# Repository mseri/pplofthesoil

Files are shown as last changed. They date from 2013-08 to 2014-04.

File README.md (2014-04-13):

# People of the Soil
**(co-winners of the London Nasa Space Apps Challenge 2013)** 

During the Space Apps Challenge 2013, at the Google Campus in London, we have developed **Project Soil**: an extremely cheap and easy to use system to collect and manage soil data.

People of the Soil in London

We kept in mind that not all the world is as lucky as us and there are plenty of places where internet is slow or completely absent and where there is much less money around. 

**Project Soil** is an open system that includes:

- an extremely cheap (~3£) digital soil testing kit to collect data, and eventually send it
- a light protocol to send the data using web, apps or even SMS and collect it on a centralised database
- an API to disseminate information via SMS or web
- a wonderful and light web application that can run on old and recent phones and gives access to the data with a simple and nice interface.

# Project Soil

We spent the first part of the challeng looking at all our different backgrounds and skills and reformulating the challenge in a series of smaller ones that we feelt we could face. 

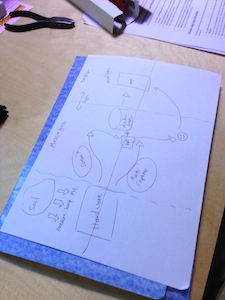
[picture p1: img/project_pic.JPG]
First drafto of Project Soil


As you can see from the image below, **Project Soil** is made by three big interlaced projects, each of them with a particular focus: acquiring data, collecting it and make it available.

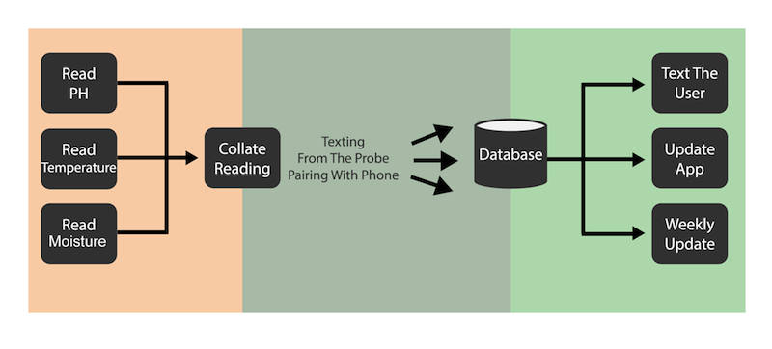
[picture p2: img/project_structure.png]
Project Soil in bites


## The probe

In this part of the projected we aimed to create a proof-of-concept soil testing kit that could be miniaturised and mass produced. This can then upload recorded soil data, taken over a period of several weeks, to a central database via a phone application or computer interface.

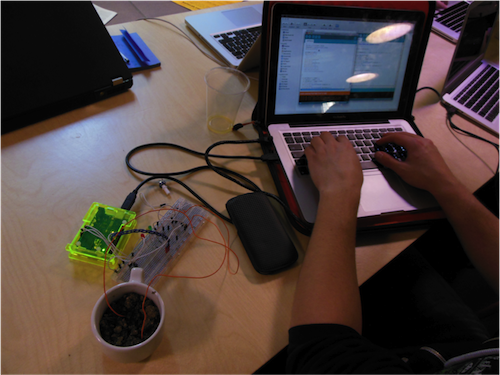
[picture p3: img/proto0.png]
The Probe v0.1


The hardware team realized in an amazingly short time a working prototype of probe to collect soil data. In the first version an Arduino was collecting data from various sensors and sending it to a Rasperry Pi programmed to forward it to our database.

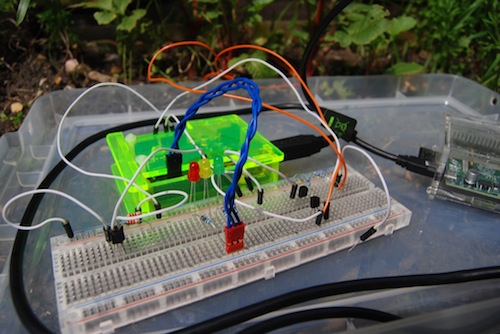
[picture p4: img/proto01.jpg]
Testing the Probe v0.1


In addition, the aim was to create a PCB schematic and layout to implement this system realistically and cost such a device. CAD models were created to aid development and concept presentation.

The project uses a DS18B20 temperature sensor and a transistor amplified simple moisture sensor.

Moisture is displayed as an estimated percentage volume of water to soil. Completely soaked soil will hold up to around 50% water content and so a measurement of resistance of pure water is taken as the calibration mark for 50% and the probe held in air is taken as the calibration for 0%.

The hardware prototype is a proof of concept, a final device should use a much cheaper MPU such as an ATMEGA48A-MU 4K memory, 8-Bit MPU. This can be sourced (in bulk) for less than 80p per unit.

### The probe and its price breakdown

In fact, from that prototype the hardware team engineered a small and cheap device that you can simply plug in the field and leave alone collecting the data. Afterward it is enough to have a USB connection to collect the data and send it to our servers.

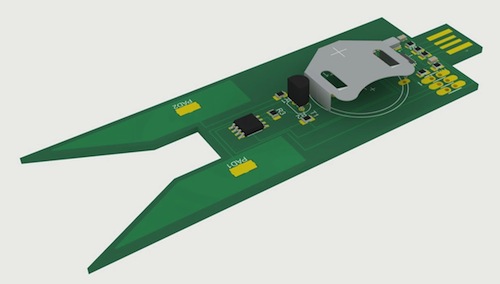
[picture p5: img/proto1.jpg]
The Probe v.1.1 - PCB


For whom may be interested, the price of the final device can be overestimated as follows:

- ATMEGA48A £0.80   
- Resistor £0.10   
- DS18B20 £0.85   
- CR2032 Coin Cell £0.39   
- Coin cell holder £0.20   
- PCB manufacture £1.00   

**Total £3.34**

## The SMS service

Keeping in mind that not all the world is covered by internet, we used the twilio API to create a service to send the data directly through SMS. This makes it good for use in more developing regions of the world.

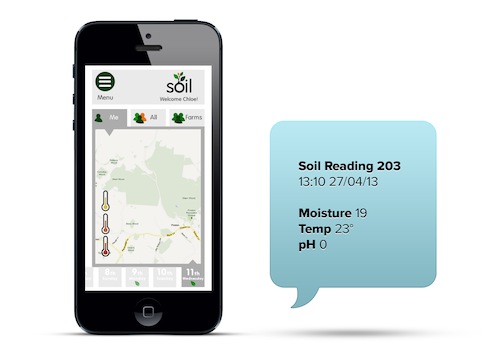
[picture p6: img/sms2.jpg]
A small screenshot of the webapp and the SMS service


Send a text to _01952 787011_ containing a list of readings for the following parameters pH, temperature, moisture, lat/latitude and long/longitude and then will be added to the dataset. The list of key, values can be separated by whitespace or , delimited and the order doesn't matter

```
pH = 7.2, lat=51.9972, long=-0.7421, temp=35
```

You will receive back a message confirming the data your sent and that it had been saved to the database.

## Data collection

While the SMS data goes directly to the database, all the rest of the communication is made by means of [MQTT](http://mqtt.org), a machine-to-machine (M2M)/"Internet of Things" connectivity protocol designed to be extremely lightweight. In this way we can move all the management of the data to our server and consume as less power and bandwith as possible on the clients.

## Web App

Again keeping in mind to consume as less bandwith as possible, we designed and developed an extremely intuitive and nice application, completely based on HTML and CSS, and with nearly no image. In this way people can access the data using any device, not just the last generation of smartphones, consuming nearly no bandwidth!

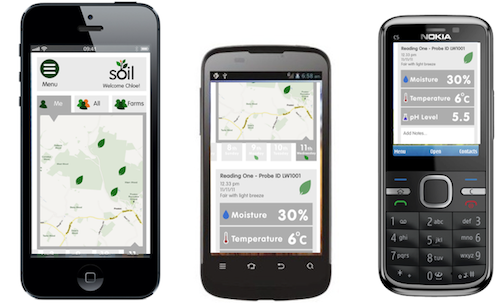
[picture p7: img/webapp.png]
Web App


You can already test our web app going to [Project Soil App](http://www.soil-app.appspot.com/)

## Ideas for the future
The possible implications and improvement for the future are the most variuos. Here there is a small list of what we could and would like to achieve:

- Implementations of more chemical and pH sensors could be made extremely cheaply and in bulk by using thick film printing processes. _This could be an avenue for further development although the technology is still heavily in it's infancy._
- Improve the probe to make it cheaper, stronger and with longer battery life.
- Add wifi/bluetooth/NFC capability to a bigger version of the probe that would not require laptop, smartphones or raspberry pi to send the data.
- Create an easy to use application to collect and send the data from probes that cannot be connected to wifi or bluetooth networks.
- Make the system independent from us and working on a global scale.
- Add some finer controls on the database to avoid fake data.
- Implement a robust and flexible API to make the soil data available to researchers and any other in need.
- Improve the Web App to include data analysis, comparisons and infographics.
- Add support to other languages.
- Go to other planet (see below).

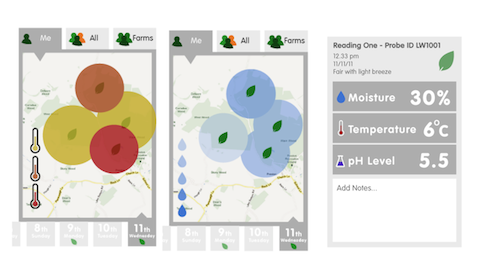
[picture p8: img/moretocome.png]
More to come on the web app


## Project Soil on other Planets
And with our small collaboration with solsola we are ready to fly on the space and collect extra terrestrial soil data!

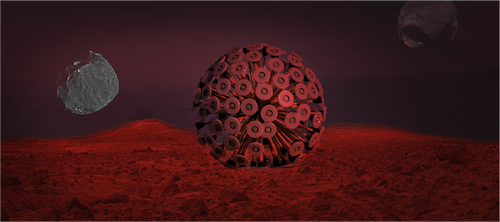
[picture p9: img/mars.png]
Solsola and Project Soil on Mars


# More Images and Informations

Look what we did going to the [Git Hub page](https://github.com/mseri/pplofthesoil), looking for our [hashtag #pplofthesoil](http://bit.ly/124FU89) on Twitter, watching our [presentation](http://bit.ly/ZIbJ3x) or reading our ["storified" weekend story](http://bit.ly/17dYVqT)

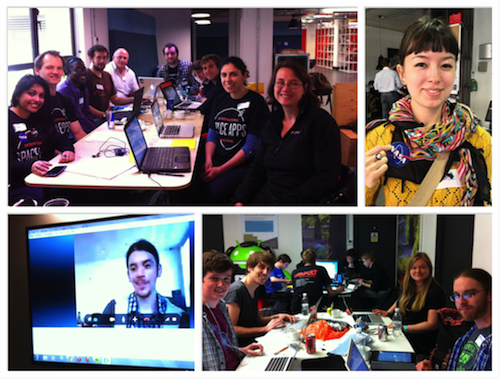
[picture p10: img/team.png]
Our Team


Additionally you can read:  
- [Our video on Vimeo](http://vimeo.com/65080796)  
- [Soil Testing Kit Challenge](http://spaceappschallenge.org/challenge/soil-testing-kit)
- [People of the Soil -- Project Page](http://spaceappschallenge.org/project/people-of-the-soil/)

Congratulation to all the [winners of the 2013 International Space Apps Challenge](http://open.nasa.gov/blog/2013/05/22/global-award-winners-for-the-2013-international-space-apps-challenge/). 
We didn't win but we've got a Honorable Mention on the Global Impact category!!!!

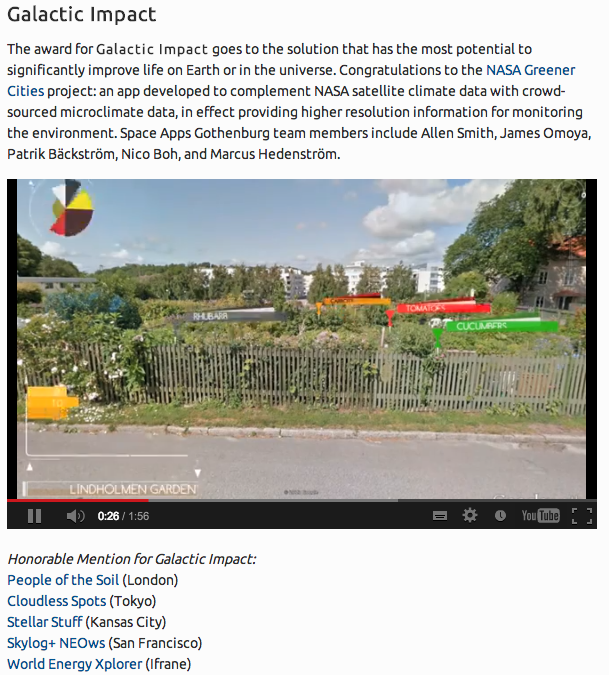
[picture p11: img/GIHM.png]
Honorable Mention for Project Soil


And thanks to Ben's committment, we have a new, nice and cheap printed Soil PCB:
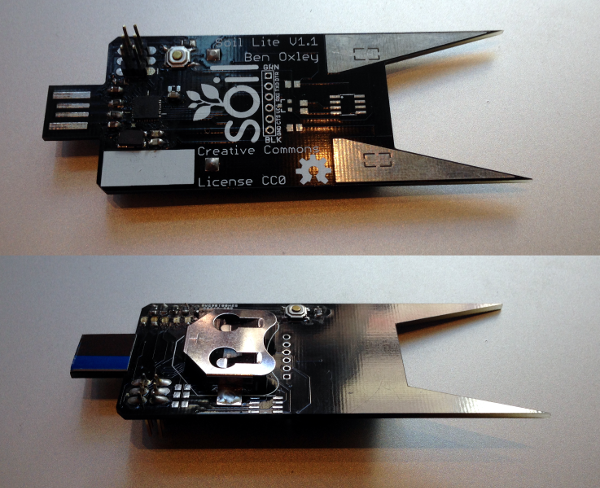
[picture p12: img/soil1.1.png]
We have a new printed version of the Soil Probe - Thanks Ben


* * * * * * * 

The Git repository contains:

- The **presentation** of our work: *SOILPres-v3.pdf*
- The full implementation of the **probe** (hardware and software) and the **PCB** schematic to build a cheap and effective probe: *probe* folder
- The interface to the **MQTT** service that translates the data and sends it to the DB: *MQTTinterface* folder
- The **DB and SMS** service (hosted on another Git repo): *text-message-and-database-api* folder
- The **mobile app** to have access to the data: *mobileapp* folder
- A folder **img** with the pictures used in this README files

The project is released under Eclipse Public License 1.0

* * * * * * * * * *    
* * * * * * * * * *    

# Something more technical for us and potential collaborators

## Data structure

Data readings are of the form  

{  
    "id": "182791",  
    "time": "13:56:13 20/04/2013",  
    "lat": "97.03125",  
    "long": "107.2890",  
    "hasAltitude":true,  
    "altitude": "10",  
    "hasPH":true,  
    "pH":"7",  
    "hasMoisture":true,  
    "moisture":"97",  
    "hasTemperature":true,  
    "temperature":"40"  
}  

and must be sent to
- MQTT Broker: m2m.eclipse.org:1833
- Topic: /pots/soil

id, time, lat, long MUST be present and not NULL, otherwise the data is sent directly to /dev/null

It can be done as simple and boring as using <http://mqtt.io/>    
Or you can let your hardware prepare the data and send it using (more or less) any programming language: <http://mqtt.org/software>

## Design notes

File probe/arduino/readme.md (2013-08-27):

# Arduino Code for PeopleOfTheSoil

It runs on an AVR with an arduino bootloader.

This project is being created in association with the google/NASA space apps challenge. 

#Roles
This part of the projected aimed to create a proof-of-concept soil testing kit that
could be miniaturised and mass produced. This can then upload recorded soil data, 
taken over a period of several weeks, to a central database via a phone application
or computer interface.

In addition, the aim was to create a PCB schematic and layout to implement this system
realistically and cost such a device.

CAD models were created to aid development and concept presentation.

#Scope
The views and conclusions contained in the software and documentation are those
of the authors and should not be interpreted as representing official policies, 
either expressed or implied, of the FreeBSD Project.

Project has used the OneWire library to communicate with a DS18B20 temperature 
sensor and a transistor amplified simple moisture sensor.

Moisture is displayed as an estimated percentage volume of water to soil. 
Completely soaked soil will hold up to around 50% water content and so a measurement 
of resistance of pure water is taken as the calibration mark for 50% and the probe 
held in air is taken as the calibration for 0%.

The hardware prototype is a proof of concept, a final device should use a much cheaper
MPU such as an ATMEGA48A-MU 4K memory, 8-Bit MPU. This can be sourced (in bulk) for 
less than 80p per unit.

##Further Work
Implementations of more chemical and pH sensors could be made extremely cheaply and in
bulk by using thick film printing processes. This could be an avenue for further 
development although the technology is still heavily in it's infancy.

## Links
* [Homepage](http://www.benoxley.com/) www.benoxley.com

<p xmlns:dct="http://purl.org/dc/terms/" xmlns:vcard="http://www.w3.org/2001/vcard-rdf/3.0#">
  <a rel="license"
     href="http://creativecommons.org/publicdomain/zero/1.0/">
    
  </a>
  <br />
  To the extent possible under law,
  <a rel="dct:publisher"
     href="www.benoxley.co.uk">
    <span property="dct:title">Ben Oxley</span></a>
  has waived all copyright and related or neighboring rights to
  <span property="dct:title">People of the Soil</span>.
This work is published from:
<span property="vcard:Country" datatype="dct:ISO3166"
      content="GB" about="www.benoxley.co.uk">
  United Kingdom</span>.
</p>

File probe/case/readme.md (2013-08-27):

#Case Designs for PeopleOfTheSoil

The 3D model is a mock up of how the final soil sensor could look. For reference, the small tab at the top represents a USB port (for connection to a phone or separate module for data transmission), the prongs at the bottom would ultimately be coated in a conductive material. The dimensions of the model are ~100 x  40 x ~17.5 mm.

In order to make it suitable for 3D printing, some compromises have been made, such as the way that prongs are flush with the bottom of the probe. As the main purpose of the model at this point is to experiment with high level design and ergonomics, these are reasonable compromises.

#Further Work

As the PCB design matures and the first prototypes are produced, the case design will be updated to simply enclose the PCB, rather than mocking-up the entire probe as it currently does. Ultimately, a cheap, 3D printed enclosure for the PCB will be considered as part of the final sensor.

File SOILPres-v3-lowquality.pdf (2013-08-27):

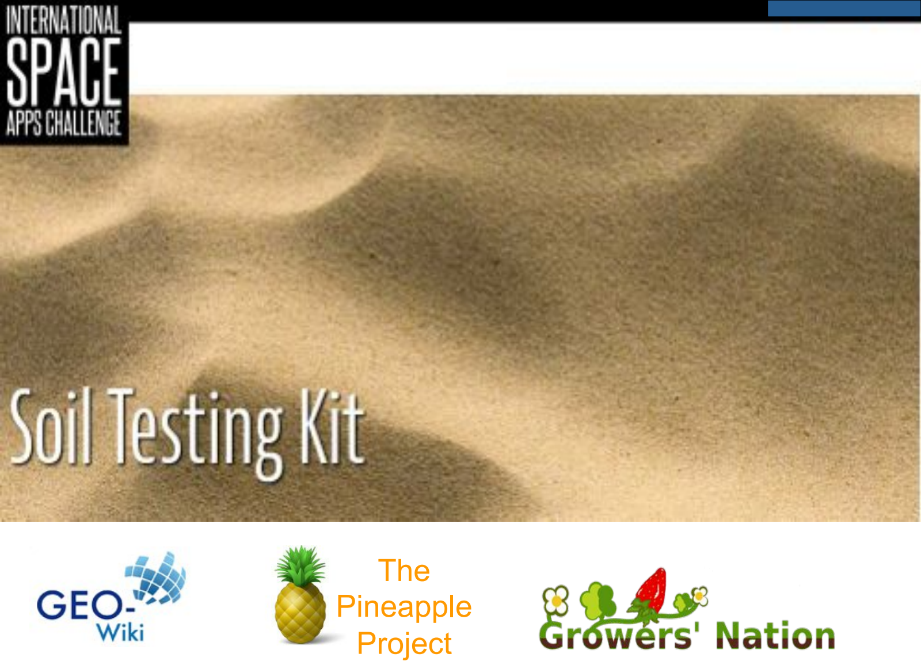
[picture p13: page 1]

## The Pineapple Project

# The Challenge

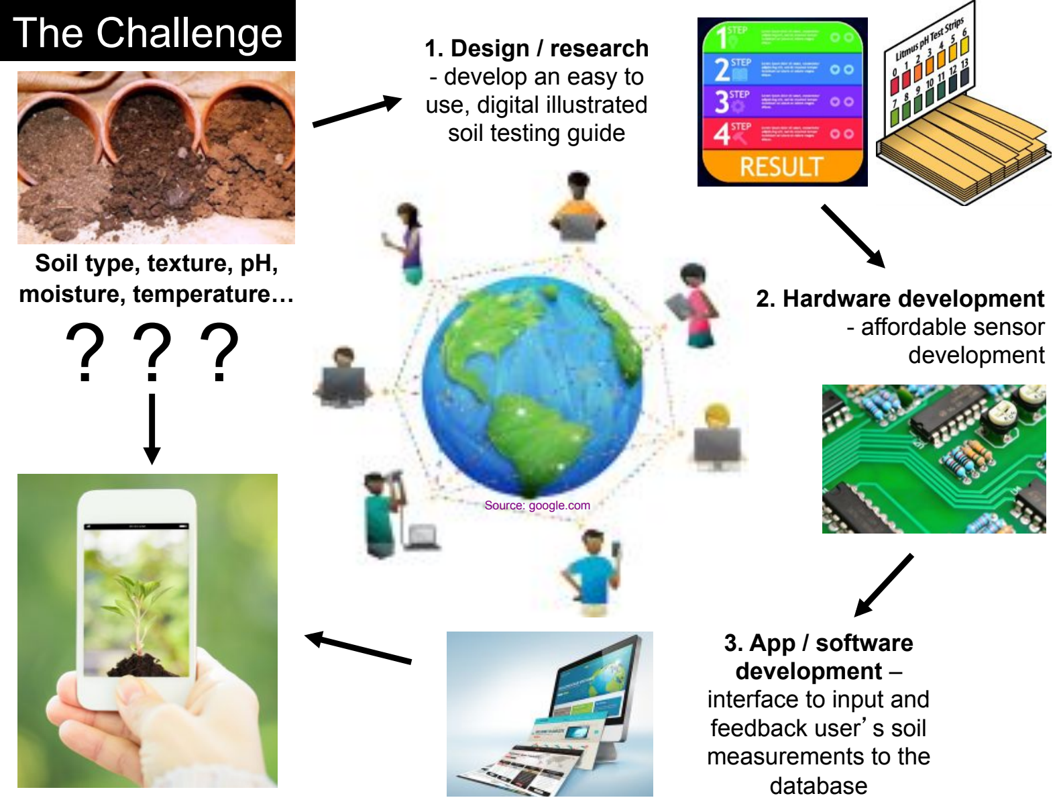
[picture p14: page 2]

Source: google.com

? ? ?

### 1. Design / research

- develop an easy to
use, digital illustrated
soil testing guide

### 2. Hardware development

- affordable sensor
development

### 3. App / software

development –
interface to input and
feedback users soil
measurements to the
database

Soil type, texture, pH,
moisture, temperature…

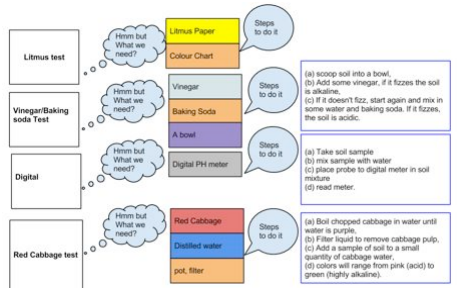
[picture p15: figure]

## New ideas have come from the development that has

happened over the hack weekend.

# Soil Test Encyclopedia Why?

# The Team

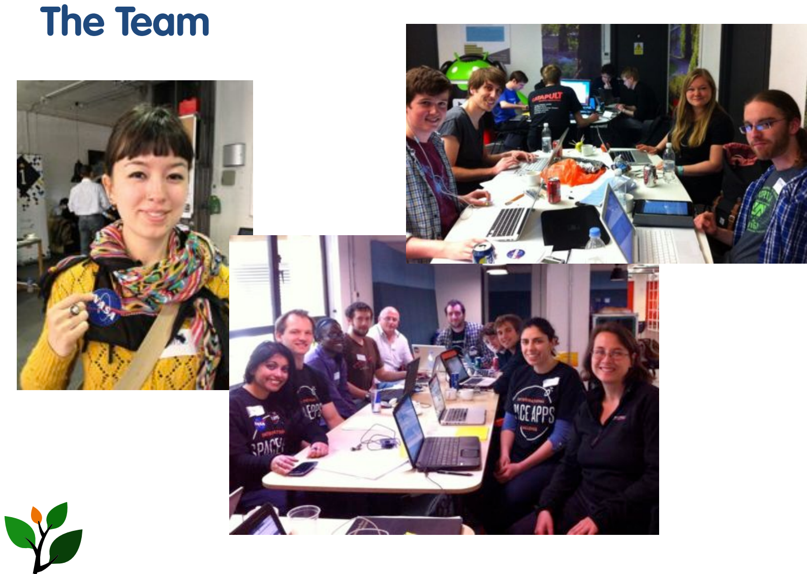
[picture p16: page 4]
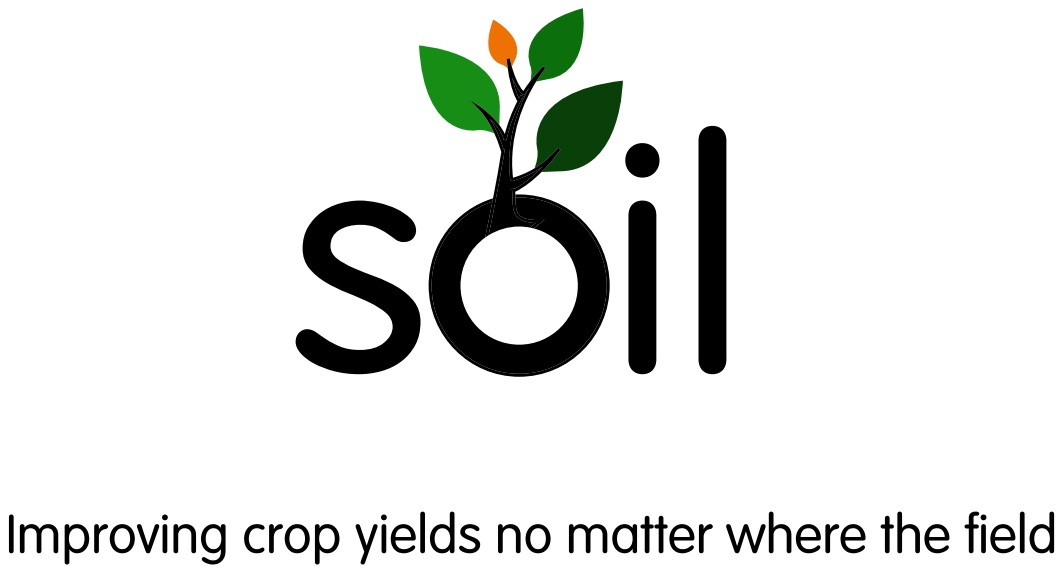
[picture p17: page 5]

Improving crop yields no matter where the field

# Aids Research

# Why?

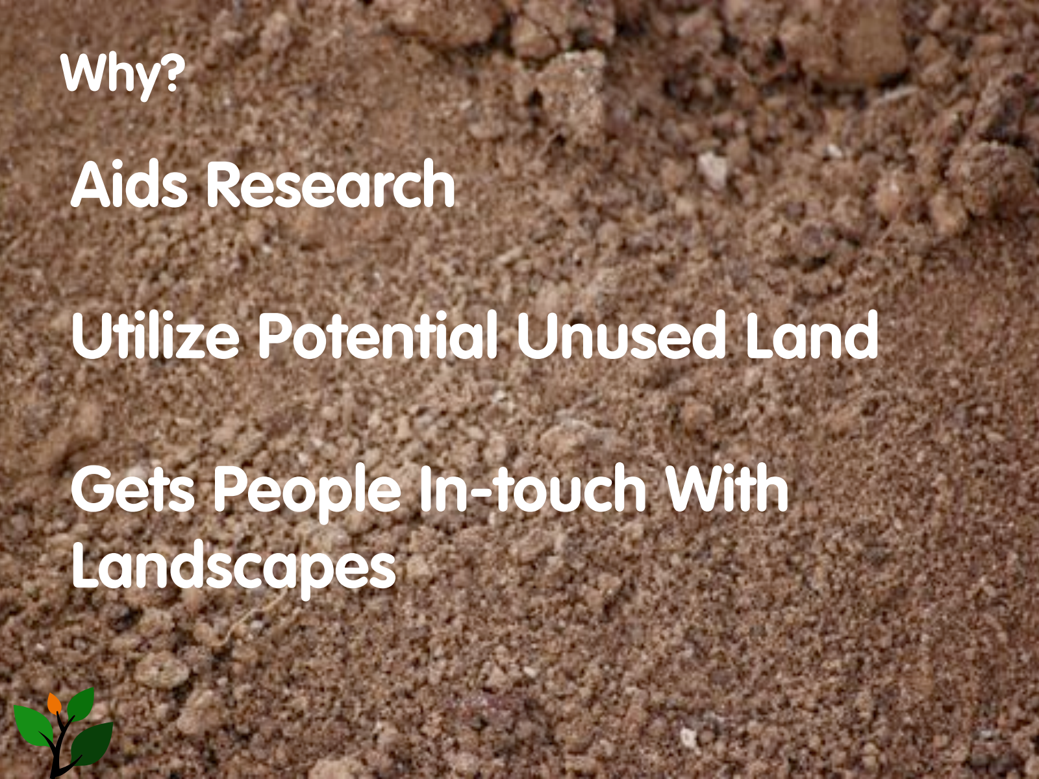
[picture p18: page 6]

# Utilize Potential Unused Land

# Gets People In-touch With Landscapes

# "People of the Soil"

# How?

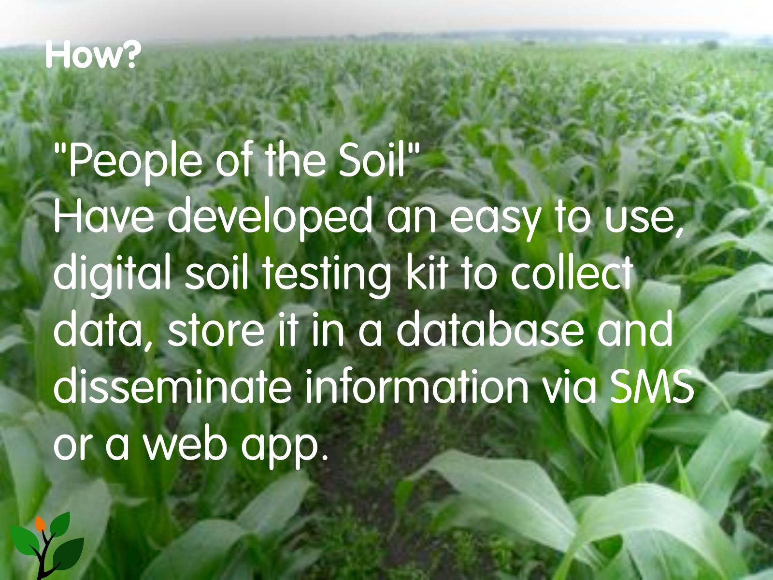
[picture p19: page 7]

Have developed an easy to use,

# digital soil testing kit to collect data, store it in a database and disseminate information via SMS

or a web app.

# How it works, how the team worked

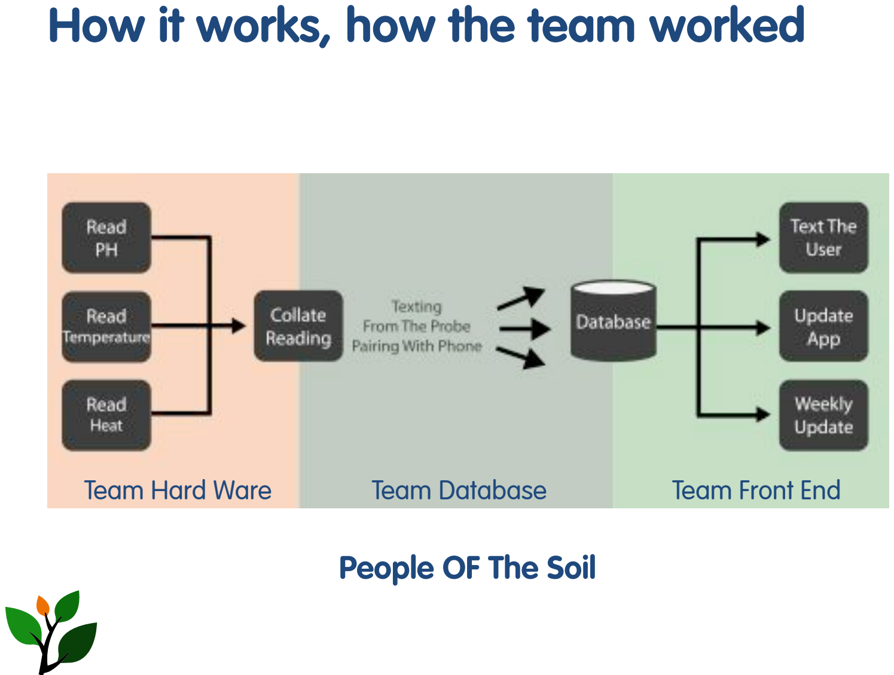
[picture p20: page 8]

Team Hard Ware | Team Database | Team Front End

## People OF The Soil

# Collaboration

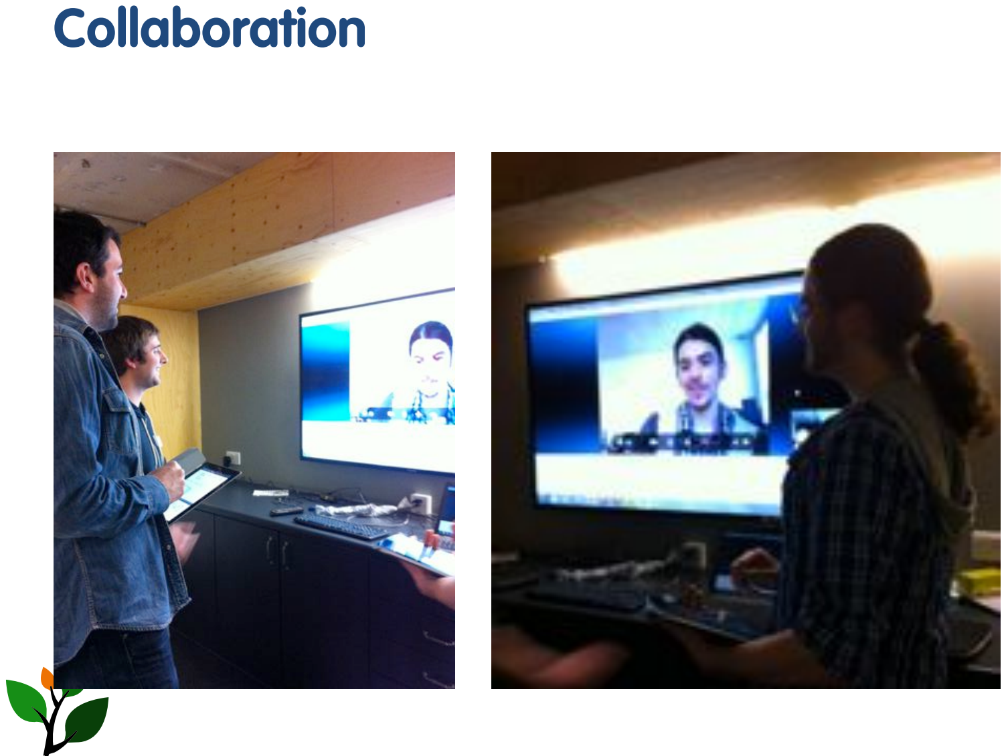
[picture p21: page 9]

# User Journey

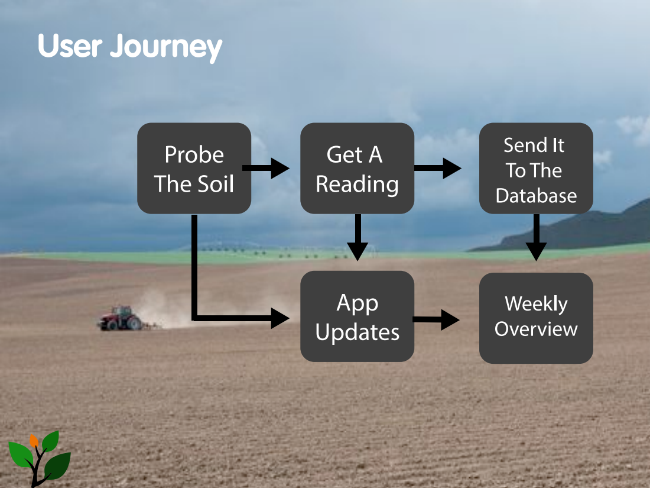
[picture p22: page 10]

# The Probe

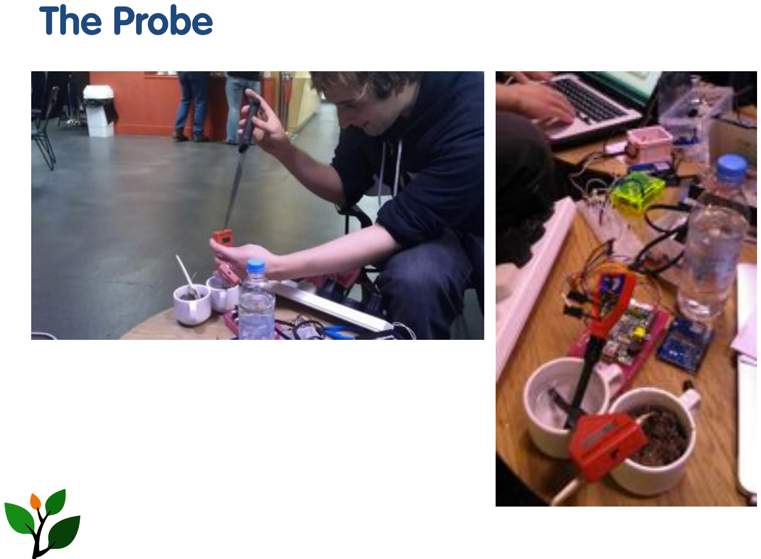
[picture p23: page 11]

# The Probe

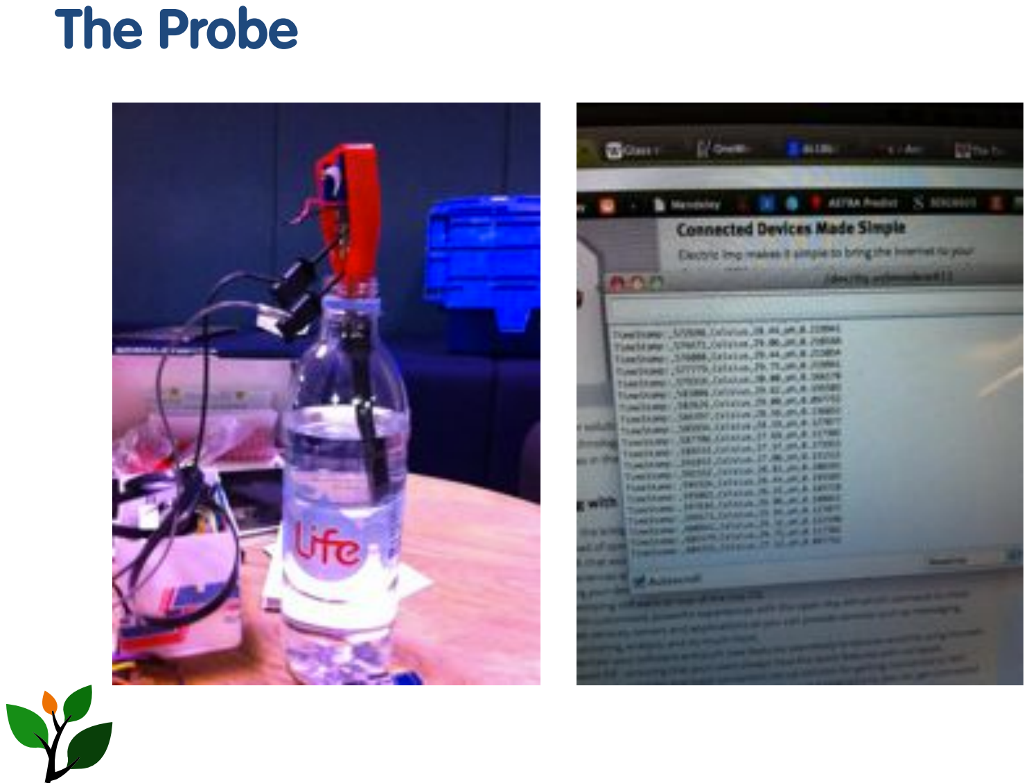
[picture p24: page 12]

# The Probe

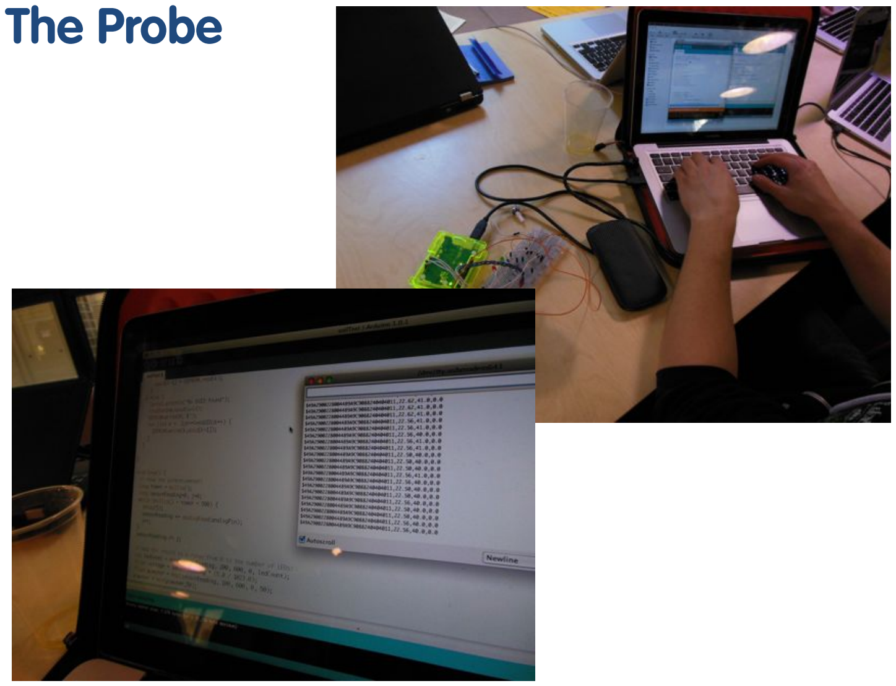
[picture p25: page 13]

# The Future Probe

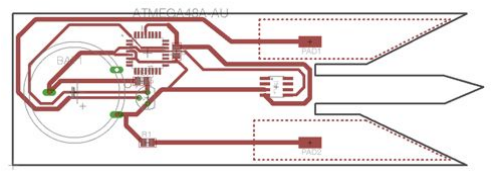
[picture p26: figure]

# The Data Base

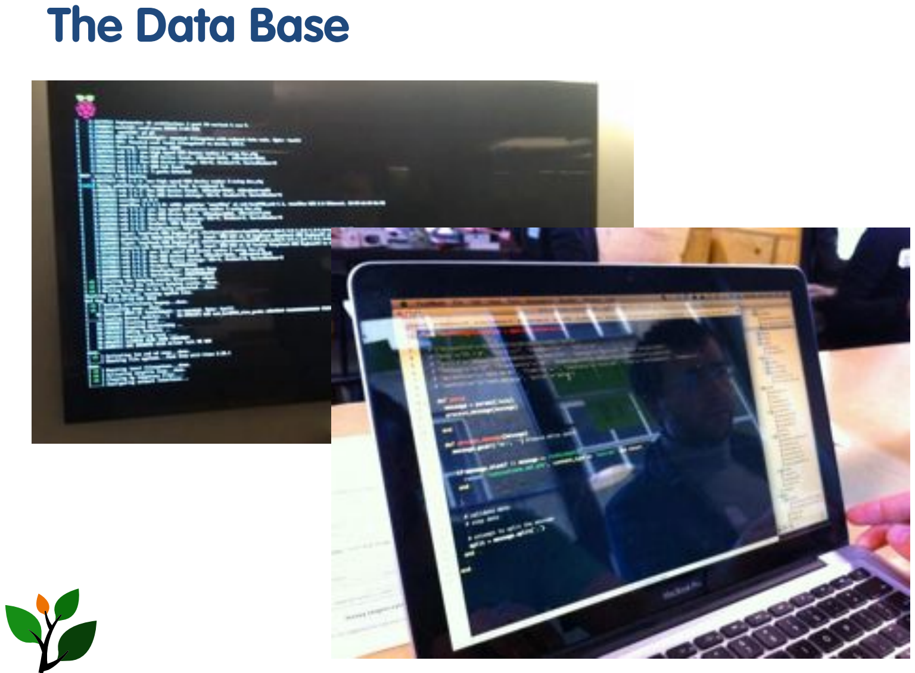
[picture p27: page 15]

# The Data Base

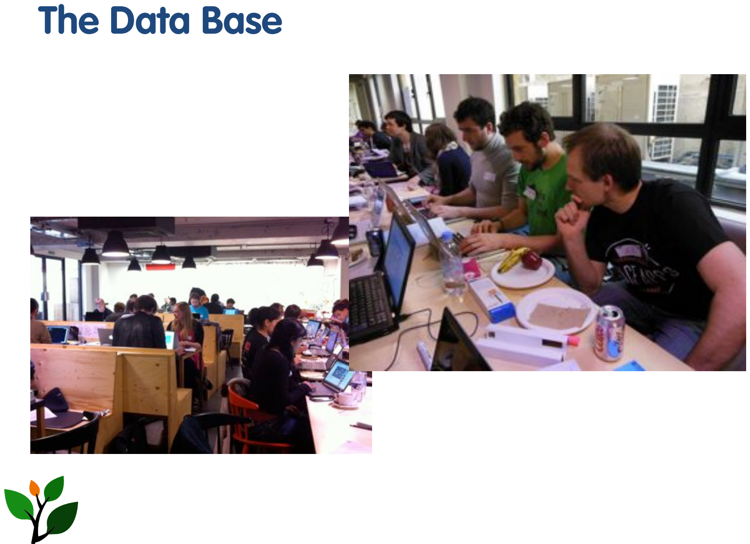
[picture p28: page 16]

# The Txt on the phone

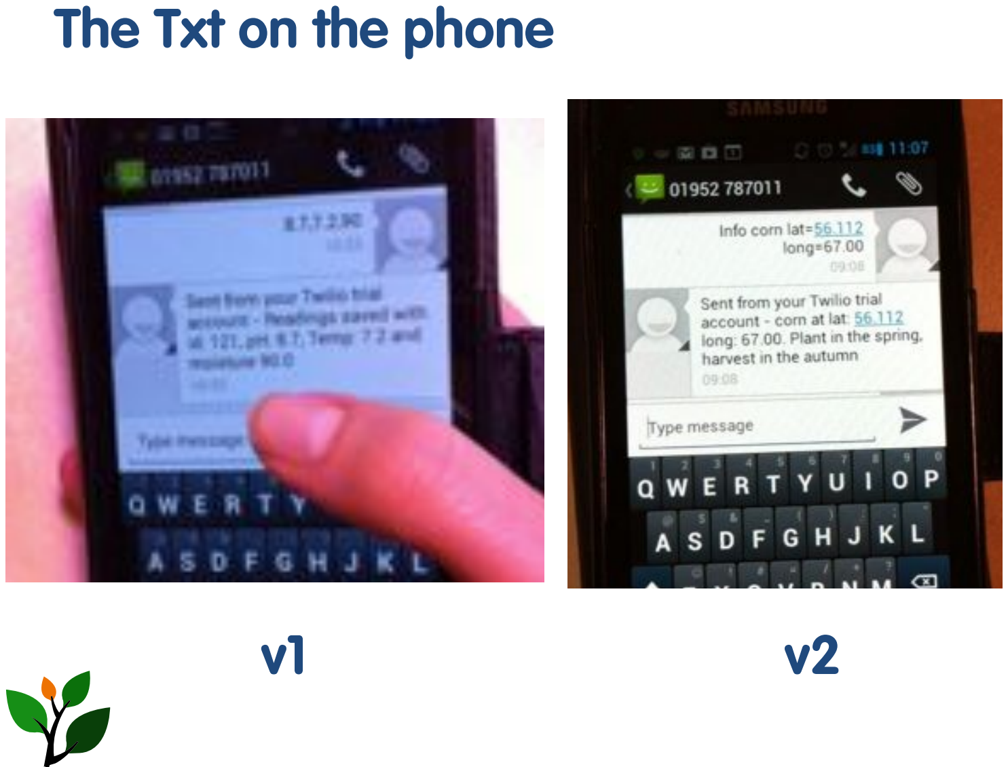
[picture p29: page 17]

v1 | v2

# Growers’ Nation

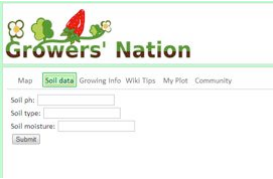
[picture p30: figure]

# The Web App

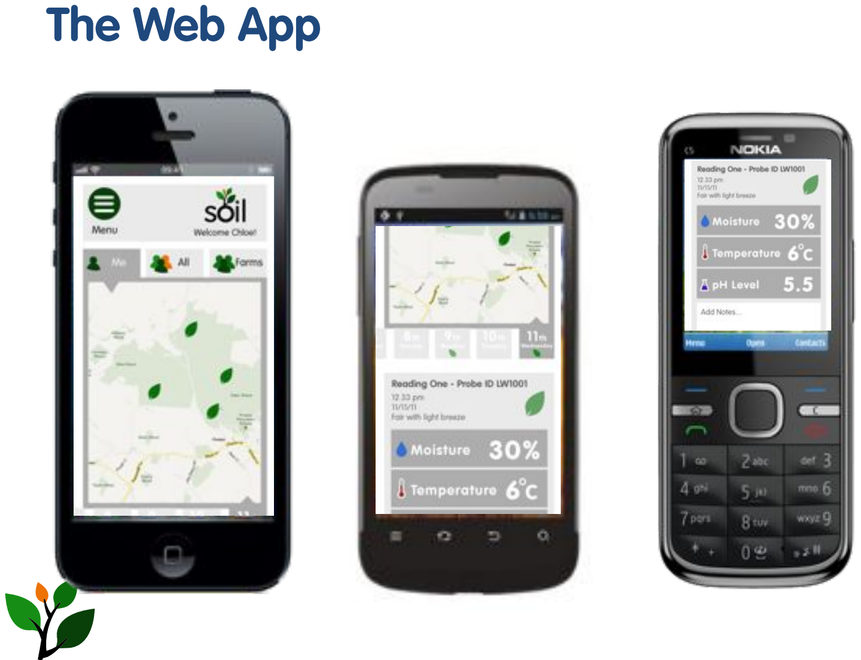
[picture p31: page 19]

# The Web App Future

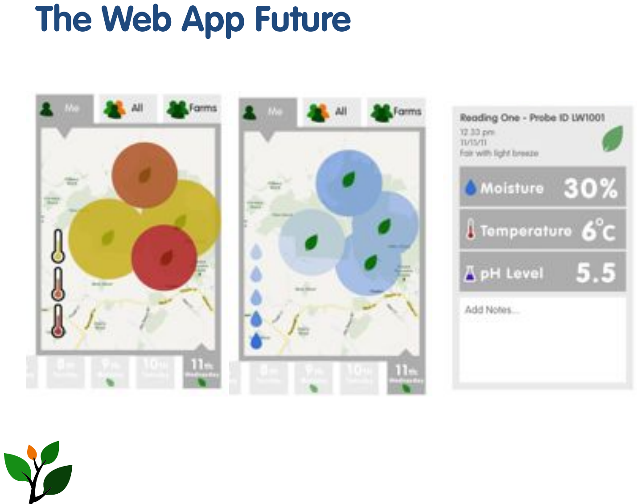
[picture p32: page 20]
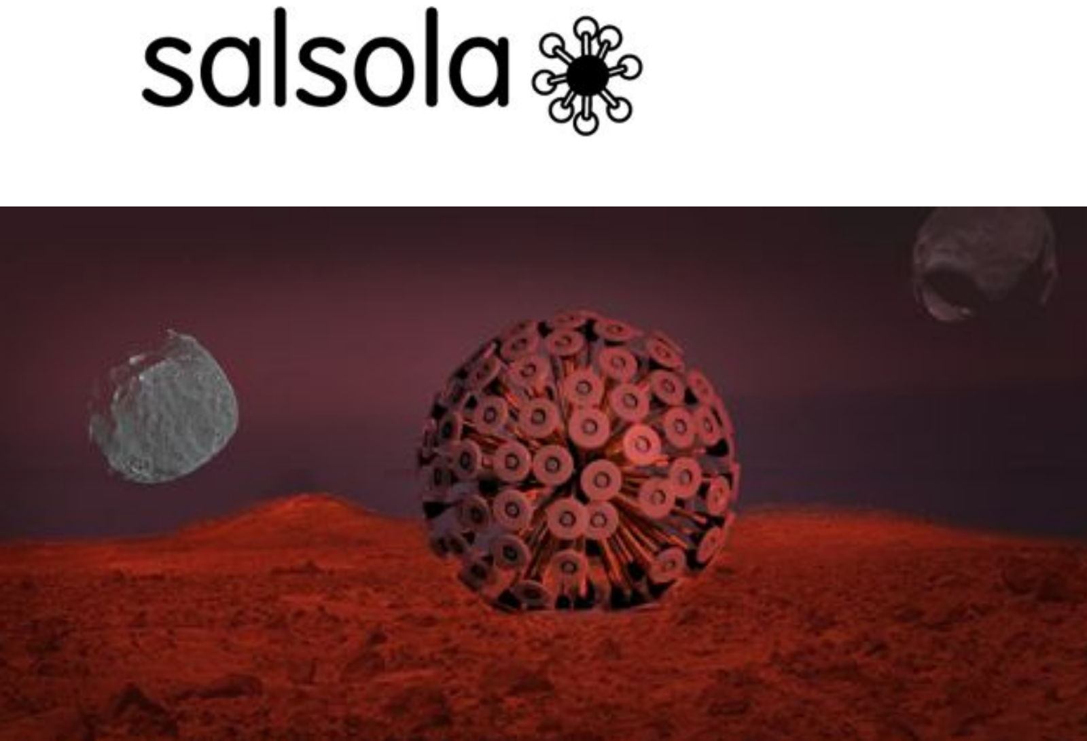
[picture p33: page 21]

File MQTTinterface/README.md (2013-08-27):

# Data acquisition module

Requirements:
- ruby >= 1.8
- mqtt gem
- json gem
- httparty gem
- daemons gem

Register to MQTT Broker: m2m.eclipse.org:1833  
Subscribe to Topic: /pots/soil/#  

* * * * * * *

**TO AVOID DUPLICATE DATA AND DB CONGESTION, PLEASE DO NOT RUN THIS SERVICE UNLESS YOU KNOW THAT THERE IS NO OTHER ACTIVE ONE. **

**AT THE MOMENT WE ARE ALREADY RUNNING ONE 24/7**

* * * * * * *

- *settings.rb* contains the global settings
- *CLIrun.rb* provides a CLI version of the listener with different level of verbosity for debug. Run simply 'ruby CLIrun.rb N', where N is 0,1 or 2 depending on the verbosity level required.
- *MQTTinterface-daemon.rb* is the background daemonized version of the listener. run with 'ruby MQTTinterface-daemon.rb [start|stop|status|reload|run]'
- *genFakeData.rb* generates a small amount of fake data for tests when probes are not connected

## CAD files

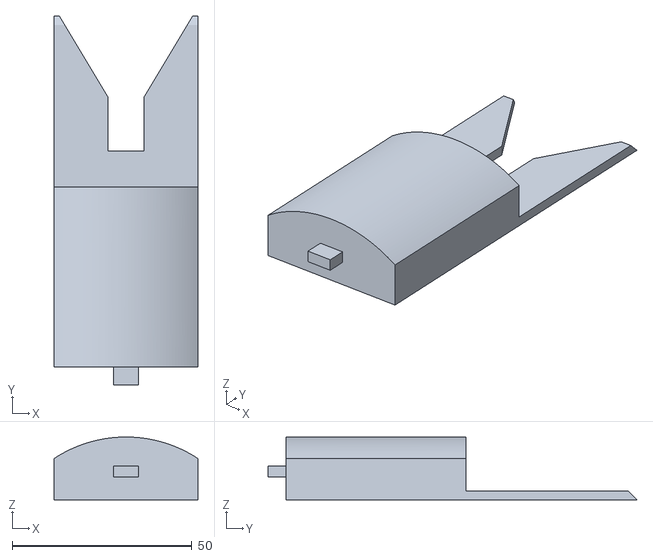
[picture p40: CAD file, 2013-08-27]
probe/case/SoilSensor.stl
40.0 x 102.5 x 17.5

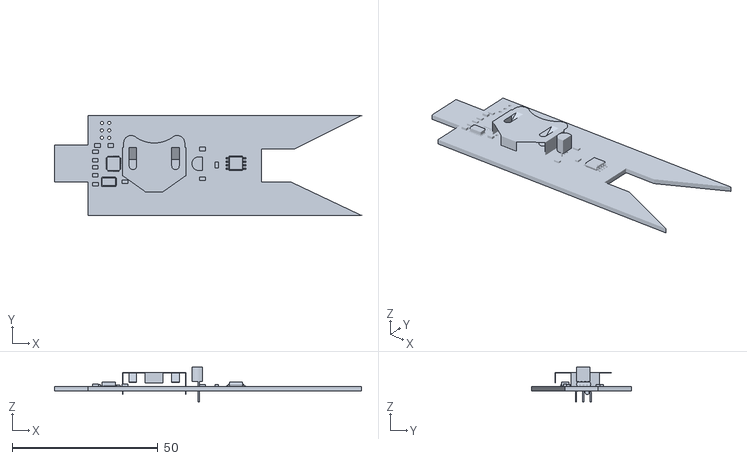
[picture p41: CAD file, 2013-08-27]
probe/eagle/stl/_.stl
105.4 x 34.3 x 11.9

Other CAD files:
probe/eagle/eagleUp/Full Model Rubberised.skp
probe/eagle/eagleUp/Full Model Rubberised~.skp
probe/eagle/eagleUp/Full Model.skp
probe/eagle/eagleUp/Full Model~.skp

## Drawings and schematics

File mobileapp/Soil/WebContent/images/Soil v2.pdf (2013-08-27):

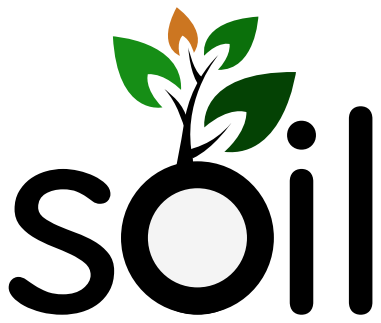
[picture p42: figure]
soil

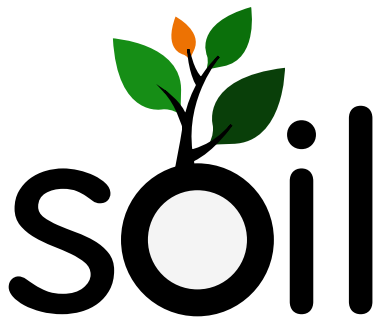
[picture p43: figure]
soil

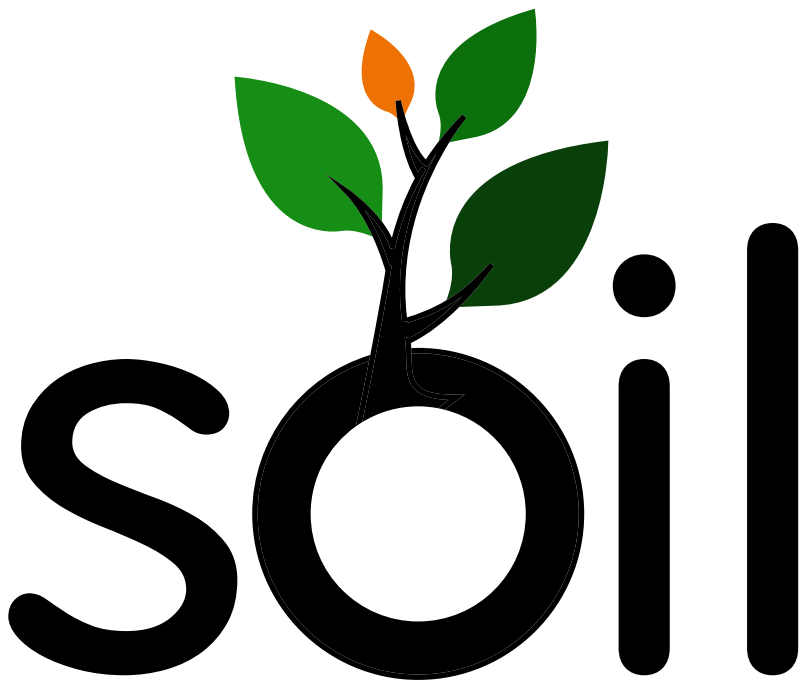
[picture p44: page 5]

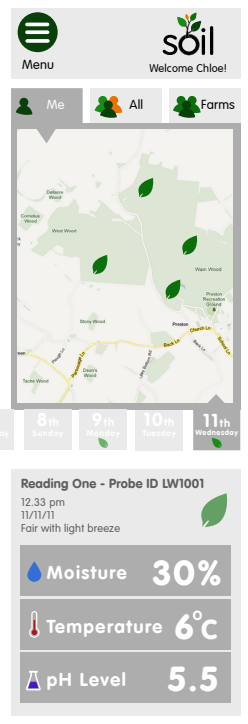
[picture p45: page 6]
Menu; Welcome Chloe!; All; Farms; Moisture; Temperature 6 C; pH Level; Wednesday; Tuesday; Monday; Sunday; Saturday

Reading One - Probe ID LW1001
Fair with light breeze

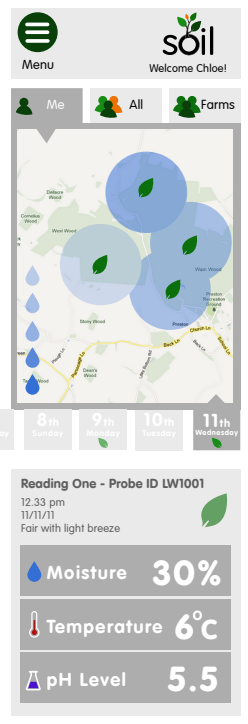
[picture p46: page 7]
Menu; Welcome Chloe!; All; Farms; Moisture; Temperature 6 C; pH Level; Wednesday; Tuesday; Monday; Sunday; Saturday

Reading One - Probe ID LW1001
Fair with light breeze

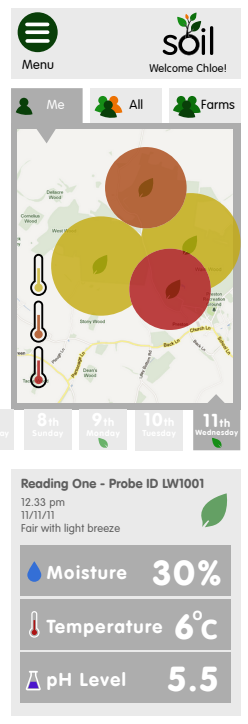
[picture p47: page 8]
Menu; Welcome Chloe!; All; Farms; Moisture; Temperature 6 C; pH Level; Wednesday; Tuesday; Monday; Sunday; Saturday

Reading One - Probe ID LW1001
Fair with light breeze

## WEATHER CACHING

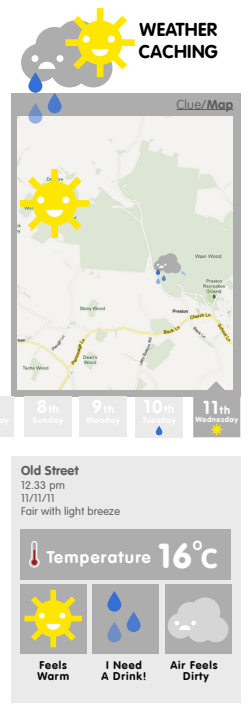
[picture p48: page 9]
Clue/Map; Temperature; Feels Warm; I Need A Drink!; Air Feels Dirty; Wednesday; Tuesday; Monday; Sunday; Saturday

Old Street
Fair with light breeze

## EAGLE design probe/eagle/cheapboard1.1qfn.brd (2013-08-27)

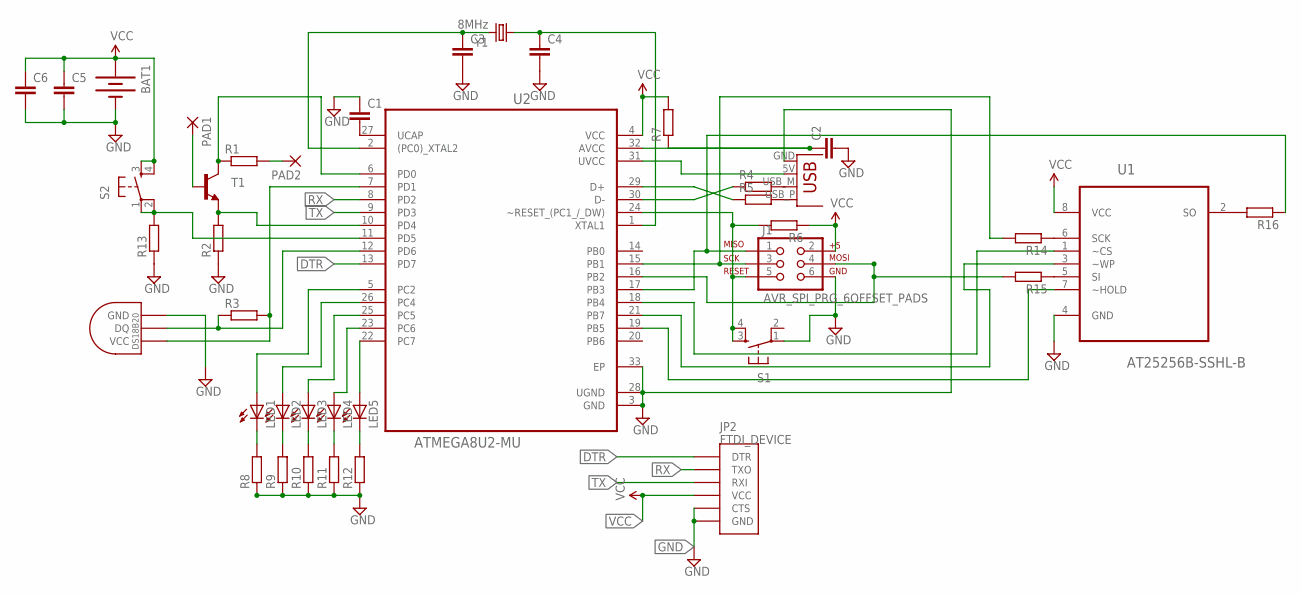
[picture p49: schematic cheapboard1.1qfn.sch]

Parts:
BAT1: BATTERY245PTH; BATTCON_245MM_PTH
C1, C2, C3, C4, C5, C6: CAP0805; 0805
J1: AVR_SPI_PRG_6OFFSET_PADS; 2X3_OFFSET
JP1: USBPCB; USB-A-PCB
JP2: FTDI_DEVICE; FTDI_DEVICE_SIDE
LED1, LED2, LED3, LED4, LED5: LEDCHIPLED_0805; CHIPLED_0805
PAD1, PAD2: SMD5; SMD2,54-5,08
R1, R2, R3, R4, R5, R6, R7, R8, R9, R10, R11, R12, R13, R14, R15, R16: R-EU_M0805; M0805
S1, S2: TAC_SWITCHSMD; TACTILE_SWITCH_SMD
T1: TRANSISTOR_NPNSOT23-3; SOT23-3
U1: AT25256B-SSHL-B; SOIC127P600X175-8N
U2: ATMEGA8U2-MU; QFN50P500X500X100-33N
U$1: DS1820SOIC; DS18B20_SOIC
Y1: 8MHz; CRYSTAL-SMD-5X3

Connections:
DTR: JP2.P$1 (DTR), U2.13 (PD7)
GND: BAT1.2 (-), C1.1, C2.2, C3.2, C4.2, C5.2, C6.2, J1.6, JP1.GND, JP2.P$5 (CTS), JP2.P$6 (GND), R2.1, R8.1, R9.1, R10.1, R11.1, R12.1, R13.1, S1.1, U1.4 (GND), U2.3 (GND), U2.28 (UGND), U2.33 (EP), U$1.GND
unnamed: R1.1, T1.3 (C), U2.6 (PD0)
unnamed: J1.4, R15.2, U2.16 (PB2)
unnamed: R2.2, T1.2 (E), U2.10 (PD4)
unnamed: J1.5, R6.2, S1.3, S1.4, U2.24 (~RESET_(PC1_/_DW))
unnamed: J1.3, R14.2, U2.15 (PB1)
unnamed: R3.1, U2.12 (PD6), U$1.DQ
unnamed: J1.1, R16.1, U2.17 (PB3)
unnamed: JP1.5V (VBUS), U2.31 (UVCC)
unnamed: C2.1, R7.1, U2.32 (AVCC)
unnamed: R4.1, U2.30 (D-)
unnamed: R5.1, U2.29 (D+)
unnamed: JP1.USB_M (D-), R4.2
unnamed: JP1.USB_P (D+), R5.2
unnamed: R3.2, U2.7 (PD1), U$1.VCC
unnamed: R14.1, U1.6 (SCK)
unnamed: C1.2, U2.27 (UCAP)
unnamed: C4.1, U2.1 (XTAL1), Y1.1
unnamed: C3.1, U2.2 ((PC0)_XTAL2), Y1.3 (2)
unnamed: LED1.A, U2.5 (PC2)
unnamed: LED2.A, U2.26 (PC4)
unnamed: LED3.A, U2.25 (PC5)
unnamed: LED4.A, U2.23 (PC6)
unnamed: LED5.A, U2.22 (PC7)
unnamed: LED1.C, R8.2
unnamed: LED2.C, R9.2
unnamed: LED3.C, R10.2
unnamed: LED4.C, R11.2
unnamed: LED5.C, R12.2
unnamed: R15.1, U1.5 (SI)
unnamed: R13.2, S2.1, S2.2, U2.11 (PD5)
unnamed: R16.2, U1.2 (SO)
unnamed: U1.1 (~CS), U2.18 (PB4)
unnamed: U1.3 (~WP), U2.21 (PB7)
unnamed: U1.7 (~HOLD), U2.19 (PB5)
PAD1: PAD1.1, T1.1 (B)
PAD2: PAD2.1, R1.2
RX: JP2.P$2 (TXO), U2.8 (PD2)
TX: JP2.P$3 (RXI), U2.9 (PD3)
VCC: BAT1.3 (+), C5.1, C6.1, J1.2, JP2.P$4 (VCC), R6.1, R7.2, S2.3, S2.4, U1.8 (VCC), U2.4 (VCC)

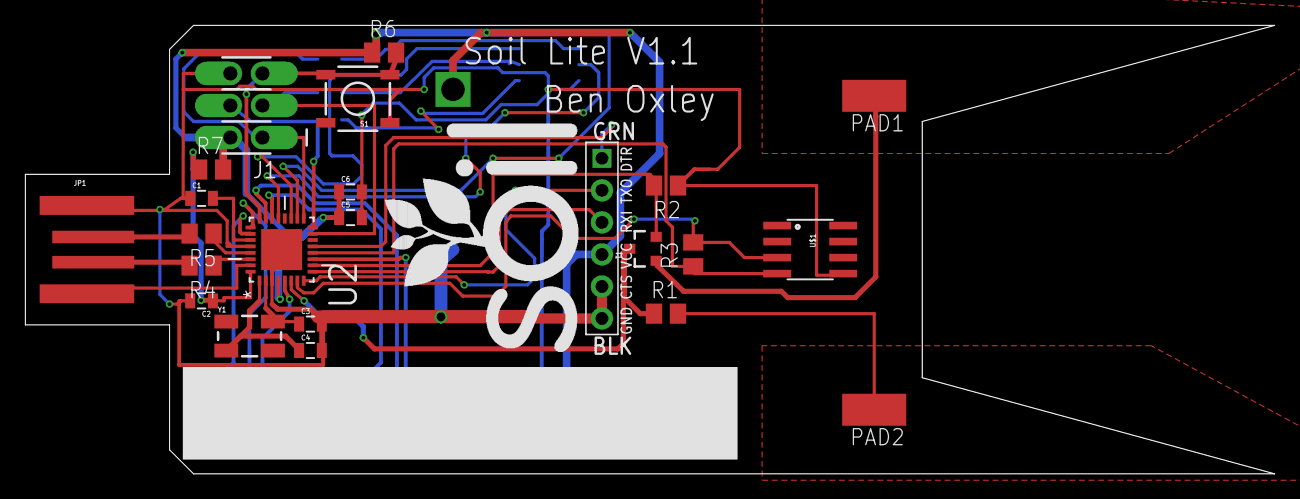
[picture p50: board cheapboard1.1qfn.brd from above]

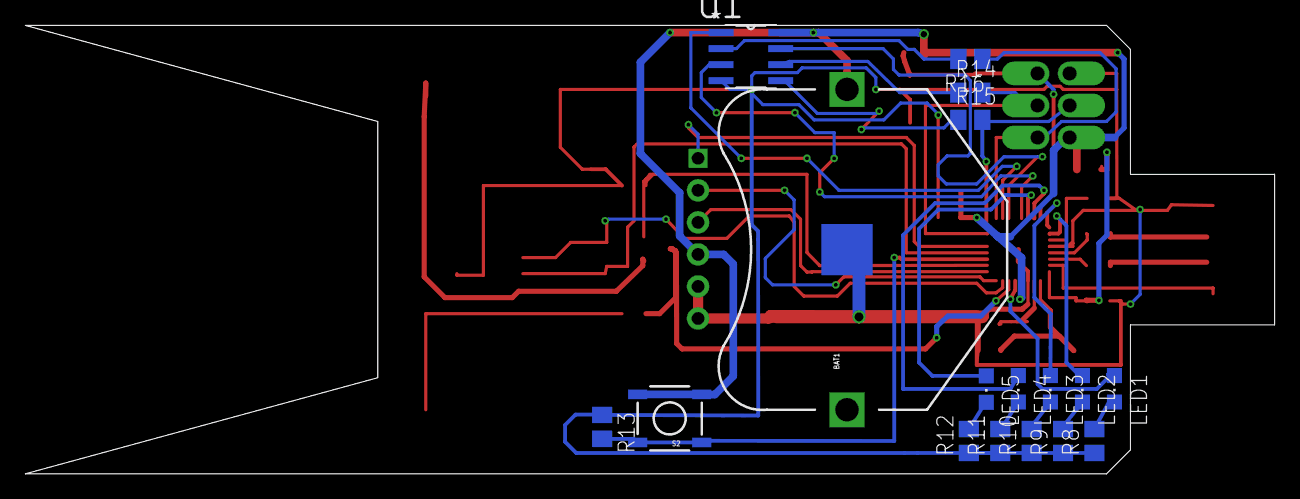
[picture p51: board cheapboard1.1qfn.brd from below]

Board: 2 copper layers, 99.1 x 35.6 mm, 40 parts (17 on the bottom side), 41 nets.

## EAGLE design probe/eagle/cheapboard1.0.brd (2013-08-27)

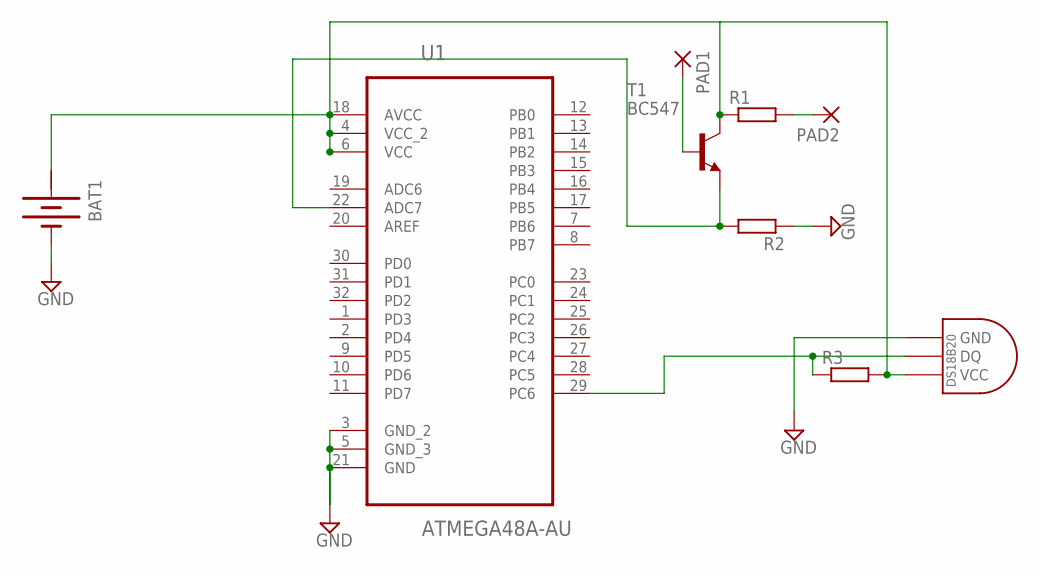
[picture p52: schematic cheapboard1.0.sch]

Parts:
BAT1: BATTERY
PAD1, PAD2: SMD5; SMD2,54-5,08
R1, R2, R3: R-EU_M0805; M0805
T1: BC547; TO92
U1: ATMEGA48A-AU; QFP80P900X900X120-32N
U$1: DS1820SOIC; DS18B20_SOIC

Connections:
+: BAT1.+@1 (+)
GND: BAT1.-, R2.1, U1.3 (GND_2), U1.5 (GND_3), U1.21 (GND), U$1.GND
unnamed: BAT1.+, R1.1, R3.2, T1.3 (C), U1.4 (VCC_2), U1.6 (VCC), U1.18 (AVCC), U$1.VCC
unnamed: R2.2, T1.1 (E), U1.22 (ADC7)
unnamed: R3.1, U1.29 (PC6), U$1.DQ
PAD1: PAD1.1, T1.2 (B)
PAD2: PAD2.1, R1.2

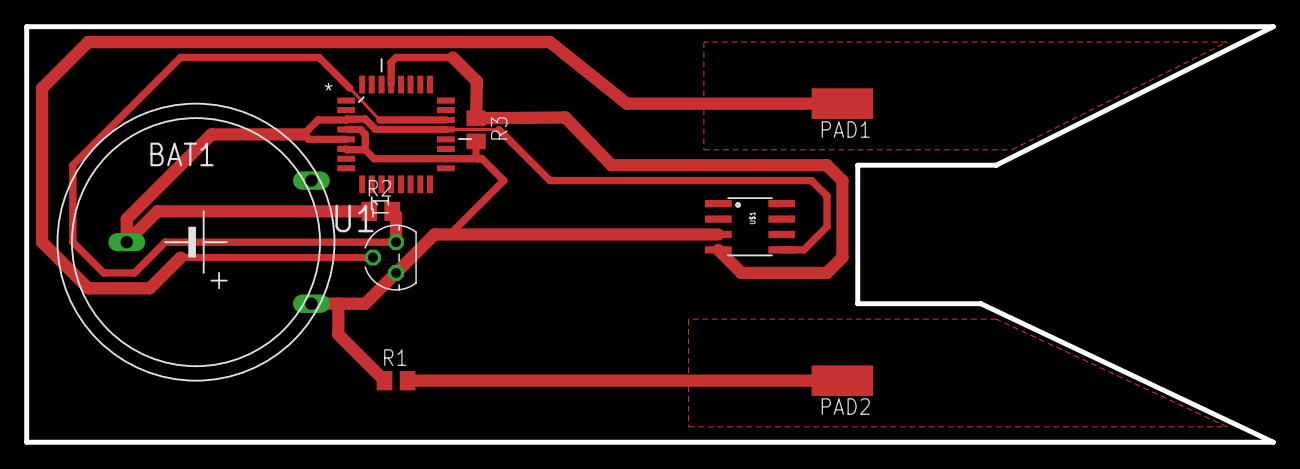
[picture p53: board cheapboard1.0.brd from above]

Board: 2 copper layers, 102.9 x 34.3 mm, 9 parts (0 on the bottom side), 6 nets.

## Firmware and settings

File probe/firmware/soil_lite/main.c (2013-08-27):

/*
Project Soil V1.1 Firmware V0.1

This program is made for Project Soil proceeding from the 
Google Space Apps Challenge. Please find more information at:
http://spaceappschallenge.org/project/people-of-the-soil/
or
https://github.com/mseri/pplofthesoil

Ben Oxley 2013

LEDs are on Pins 22(PC7),23(PC6),25(PC5),26(PC4) and 5(PC2)
*/

#include <avr/io.h>
#include <stdio.h>
#include <util/delay.h>
#include <avr/eeprom.h>
#include <avr/interrupt.h>
#include <string.h>
#include <stdbool.h>
#include <stdlib.h>
#include <avr/wdt.h>

#define output_low(port,pin) port &= ~(1<<pin)
#define output_high(port,pin) port |= (1<<pin)
#define set_input(portdir,pin) portdir &= ~(1<<pin)
#define set_output(portdir,pin) portdir |= (1<<pin)

void delay_ms(uint8_t ms) {
	uint16_t delay_count = F_CPU / 17500;
	volatile uint16_t i;

	while (ms != 0) {
		for (i=0; i != delay_count; i++);
			ms--;
	}
}

int main(void)
{
	DDRC |= 0xFF;
	while(true){
	  output_high(PORTC, PC7);
      _delay_ms(500);
      output_low(PORTC, PC7);
      _delay_ms(500);
	}
	return 0;
}

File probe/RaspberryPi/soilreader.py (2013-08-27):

# People of the Soil
# Data acquisition and upload script
# v0.1
#
# Written by Stephen Lewis (mail@stephen-lewis.me.uk)
#
# Licensed under the Eclipse Public License v1.0
# http://www.eclipse.org/legal/epl-v10.html
#
# Revision history
# 2013-04-20 14:10		File created		STFL

import serial
import time
import netifaces
#import pygeoip
import io
import string
import mqttpublisher

#port_name = '/dev/ttyUSB0'
#port_name = '/dev/tty.usbmodemfd121'
port_name = '/dev/ttyACM0'

# configure and open serial port for data read
try:
	serial_port = serial.Serial(port_name, baudrate=9600) # assume stopbits=1 bytesize=8 parity='N'
except serial.SerialException:
	print("Unable to open serial port: aborting.\n");
	exit();

if serial_port.isOpen() != True:
	serial_port.open()
	if serial_port.isOpen() != True:
		print("Unable to open serial port: aborting.\n");
		exit()

# read and upload the data: forever
while True:
	# assume format: $<device id>,<temperature>,<moisture>,<pH>\n
	data_list = None
	while data_list == None:
		data = serial_port.readline()
#		print data
		data_list = string.split(data, ',')

	if len(data_list) < 4:
		continue

	device_id = data_list[0]
	temperature = data_list[1]
	moisture = data_list[2]
	pH = data_list[3]

	# fetch timestamp
	timestamp = time.strftime('%X %x %Z')

	#####
 	# Nasty way to find the location
 	#  - maybe replace with cheap GPS in device?

	# fetch IP, and from that GEOIP Data
	#net_dict = netifaces.ifaddresses('wlan0')
#	net_dict = netifaces.ifaddresses('en0')
	#print net_dict
#	ip_dict = net_dict[2]
#	ip_addr = ip_dict[0]["addr"]
	#print ip_addr

	#city_db_path = '/usr/share/GeoIP/GeoIPCity.dat'
#	city_db_path = './GeoIPCity.dat'
#	geoip = pygeoip.GeoIP(city_db_path)
#	geoip_dict = geoip.record_by_addr(ip_addr)
	#print geoip_dict
#	if geoip_dict != None:
#		latitude = geoip_dict["latitude"]
#		longitude = geoip_dict["logitude"]
#	else:
	latitude = '51.522833'
	longitude = '-0.085179'

	# End nasty location finding
	#####

	# build JSON and publish to MQTT
	json = "{\n"
	json += "\"id\" : \"" + device_id + "\",\n"
	json += "\"time\" : \"" + timestamp + "\",\n"
	json += "\"lat\" : \"" + latitude + "\",\n"
	json += "\"long\" : \"" + longitude + "\",\n"
	json += "\"hasAltitude\" : false,\n"
	if pH == 'NULL':
		json += "\"hasPH\" : false,\n"
	else:
		json += "\"hasPH\" : true,\n"
		json += "\"pH\" : \"" + pH + "\",\n"
	if moisture == 'NULL':
		json += "\"hasMoisture\" : false,\n"
	else:
		json += "\"hasMoisture\" : true,\n"
		json += "\"moisture\" : \"" + moisture + "\",\n"
	if temperature == 'NULL':
		json += "\"hasTemperature\" : false,\n"
	else:
		json += "\"hasTemperature\" : true,\n"
		json += "\"temperature\" : \"" + temperature + "\"\n"
	json += "}"

#	print json

	mqttpublisher.sendSensorData(json)

# EOF

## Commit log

2013-04-20 Added arduino code
2013-04-20 Added arduino readme
2013-04-20 correction of comments… nothing important
2013-04-20 Adding RaspberryPi files.
2013-04-20 Updated readme for arduino
2013-04-21 Added UUID for arduino device, updated license file to CC0
2013-04-21 Added pcb files
    [cheapboard1.0.brd, cheapboard1.0.sch]
2013-04-21 Added PCB readme
2013-04-22 Updated Readme. Added Presentation. Small reshaping of the folder structure
    [cheapboard1.0.brd, cheapboard1.0.sch]
2013-04-24 Added many many new PCB files
    [cheapboard1.0.brd]
2013-04-24 Added many many files
    [Full Model Rubberised.skp, Full Model Rubberised~.skp, Full Model.skp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]
2013-04-29 Adding STL files and images for probe case prototype.
    [SoilSensor.stl]
2013-04-30 Added readme to probe case section.
2013-05-06 Added final design for v1.1 manufacture
    [cheapboard1.1.brd, cheapboard1.1qfn.brd, cheapboard1.1qfn.sch]
2013-08-27 We've got an Honorable Mention! :)
    [Full Model Rubberised.skp, Full Model Rubberised~.skp, Full Model.skp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]

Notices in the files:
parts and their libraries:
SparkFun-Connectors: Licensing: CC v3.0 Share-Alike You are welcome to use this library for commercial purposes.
